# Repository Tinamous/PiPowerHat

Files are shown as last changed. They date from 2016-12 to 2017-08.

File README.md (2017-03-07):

Raspberry Pi Power Hat
======================

WORK IN PROGRESS - Not tested!

A Hat for the Raspberry Pi to supply 5V though the 40pin header from a 7-36V DC source rather than using the USB plug.

When using the 7" Pi Display the voltage drop across the USB cable (esp. if long) may be too much for the Pi. This hat allows a higher voltage to be dropped 
right as it is needed and distributed to the Pi and the display so reducing the voltage drop.

Rather than design and source a buck switching supply this hat uses one of the many cheap "eBay" buck converts that have the 
standard 7805 footprint (Don't use an actual 7805!).

e.g. a PM-5033-1 36 V In, 5V 2.5A Out buck converter. http://www.ebay.co.uk/itm/262241859833

The PCB also includes:
* INA219 to measure the power via a current sense resistor (R4 - value to be determined)
* The normal Pi HAT EEprom
* DS18B20 - SOIC 8 footprint by the converter to monitor PCB temperature.
* DS18B20 - TO-92 (3 Pin) to measure ambient temperature
* 3 Pin Molex header for off-board DB18B20's
* 4 Pin Molex header for Pi 7" display (GND, 5V, I2C connections).

Pi Hat original schema/PCB (connector, shape, EEprom) but Ivan Zilic (http://www.flyfish-tech.com)
Source: 
https://www.raspberrypi.org/forums/viewtopic.php?f=100&t=82618
http://www.flyfish-tech.com/pub/RasPi-BplusHAT.zip

Component Libraries:
SparkFun - https://github.com/sparkfun/SparkFun-Eagle-Libraries
DS18B20-SOIC - ??
INA219 - Farnell

See https://github.com/Tinamous/OctoPrint-PiPower for an OctoPrint plugin to monitor and control.

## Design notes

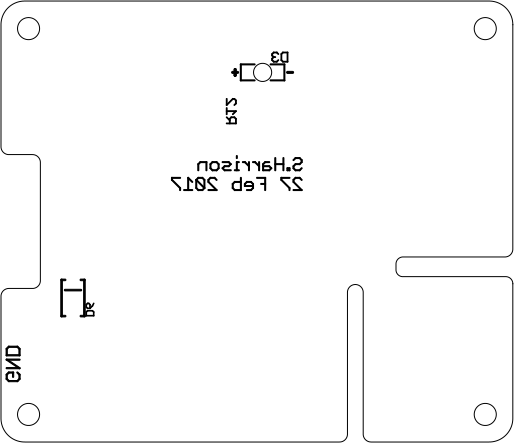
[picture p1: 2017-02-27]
Images/V1.2/bottom_silkscreen.png

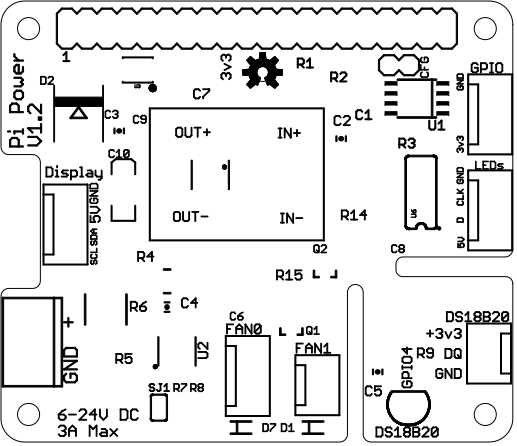
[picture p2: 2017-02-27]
Images/V1.2/top_silkscreen.png

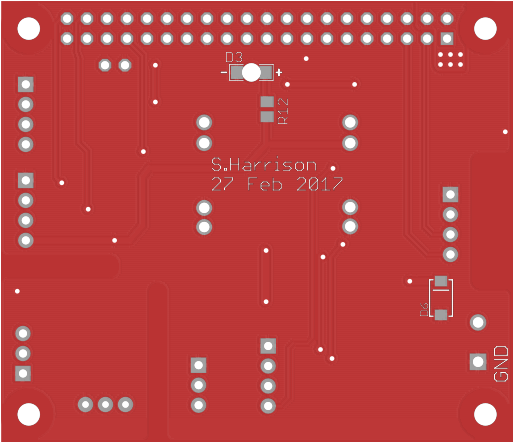
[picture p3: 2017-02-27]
Images/V1.2/bottom.png

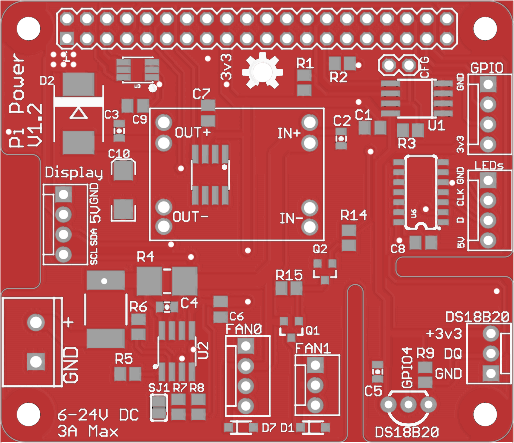
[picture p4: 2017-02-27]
Images/V1.2/top.png

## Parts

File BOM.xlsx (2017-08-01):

Big Lathcing Relat. Version 1. Bill of Materials
Part | Value | Case | QTY | Price Each | Price Total | Farnell Part Number | Reel | Mouser | Notes
C5 | 1uF | "0805" | 1 | 0.0291 | 0.0291 | 2320853 | 2310412
C1 | 10uF Tant | "Case A" | 1 | 0.106 | 0.106 | 1457413
R1 | 1k5 | "1206" | 1 | 0.0013 | 0.0013 | 9335951 | 2129658
D2 | Reverse LED Blue | "1206" | 1 | 0.23 | 0.23 | 2217907
CONN1 | USB A Plug |  | 1 | 0.35 | 0.35 | 2476092
JP1 | 3 Way terminal block | header | 1 | 0.107 | 0.107 | 2493690
JP1b | 3 Way terminal block | pluggable-12AWG | 1 | 0.267 | 0.267 | 2493638
U1 | Latching relay |  | 1 | 2.16 | 2.16 | 2432863
U2 | Photon or Electron |  | 0 | 20 | 0
U2a | Headers 12W |  | 2 | 0.0911 | 0.1822 | 1593465
U2b | Headers 18W |  | 0 | 1.11 | 0 | 1801220
U3 | BD6211F-E2 |  | 1 | 1.05 | 1.05 | 1716259
 | PCB |  | 1 | 1.5 | 1.5
 |  |  |  |  | 5.9826
 |  |  |  | Wholesale: | 11.9652
 |  |  |  | Retail | 23.9304

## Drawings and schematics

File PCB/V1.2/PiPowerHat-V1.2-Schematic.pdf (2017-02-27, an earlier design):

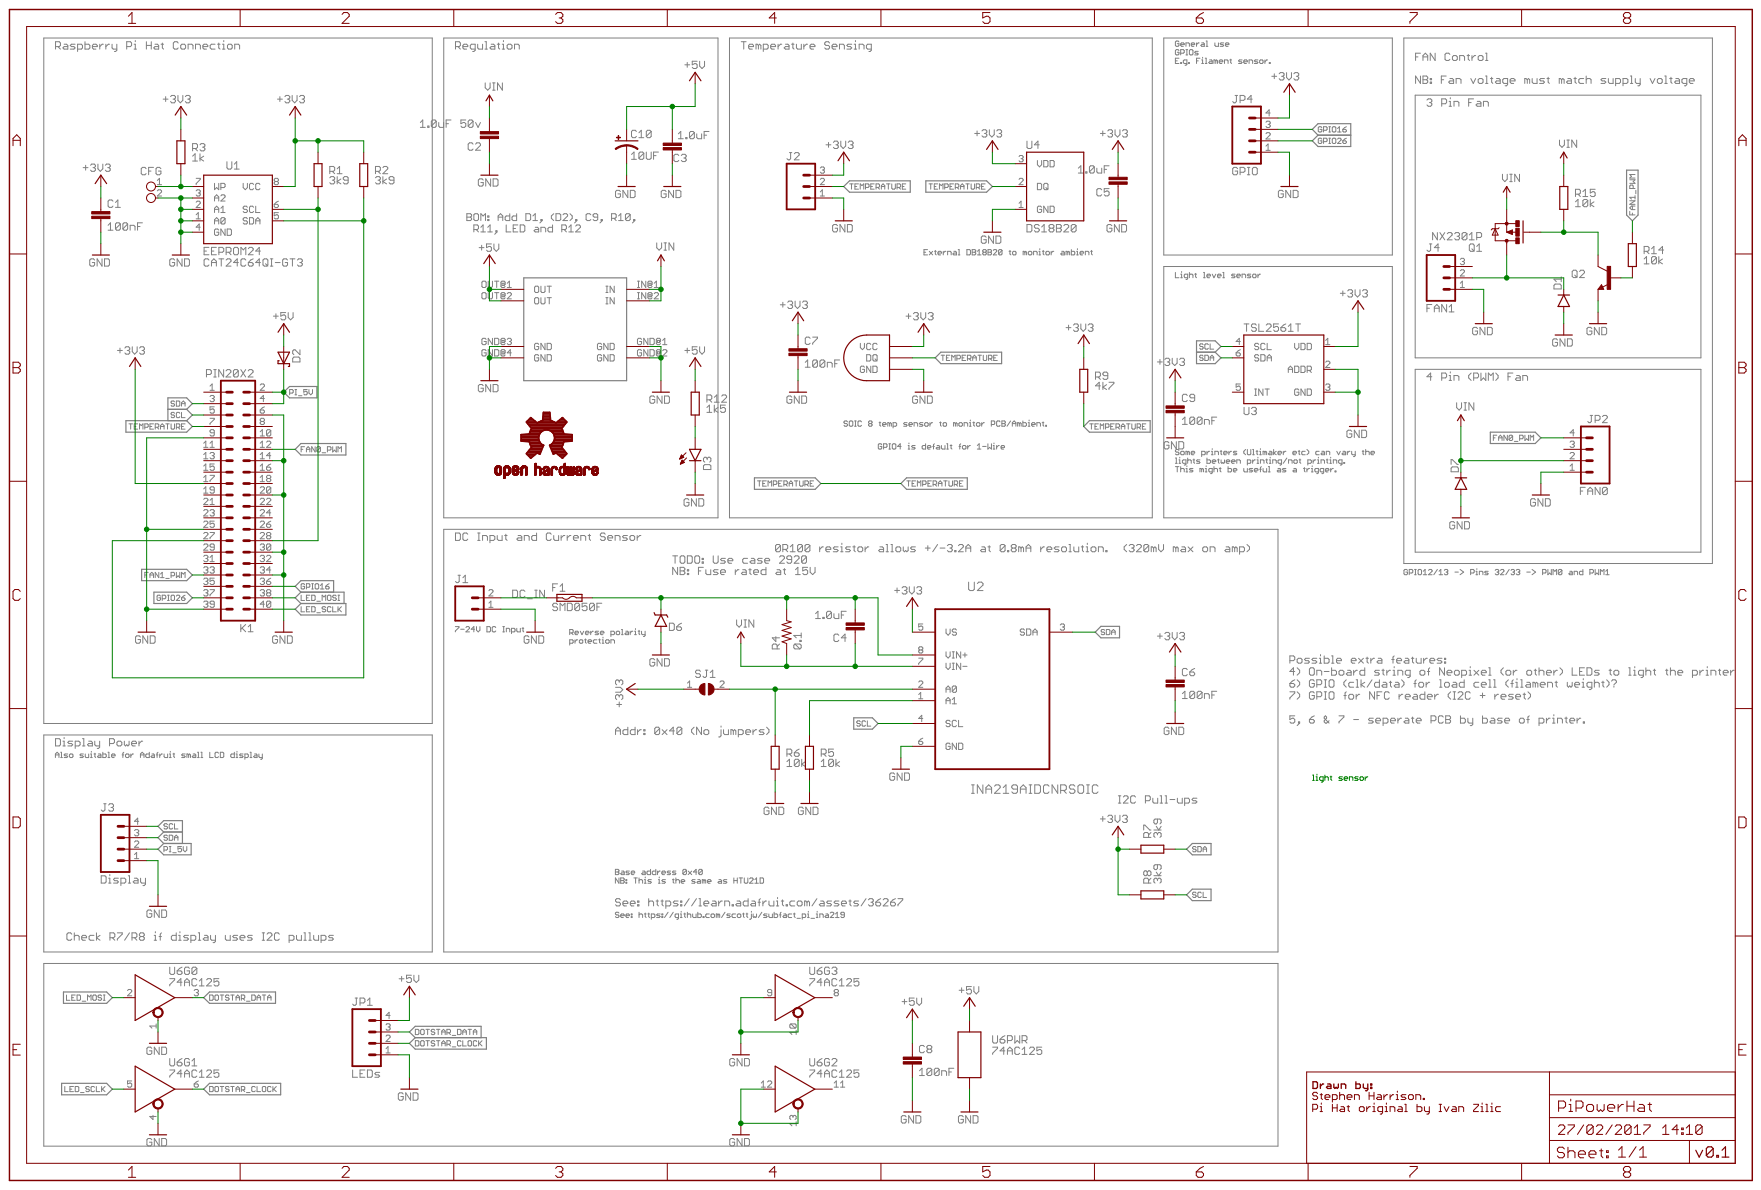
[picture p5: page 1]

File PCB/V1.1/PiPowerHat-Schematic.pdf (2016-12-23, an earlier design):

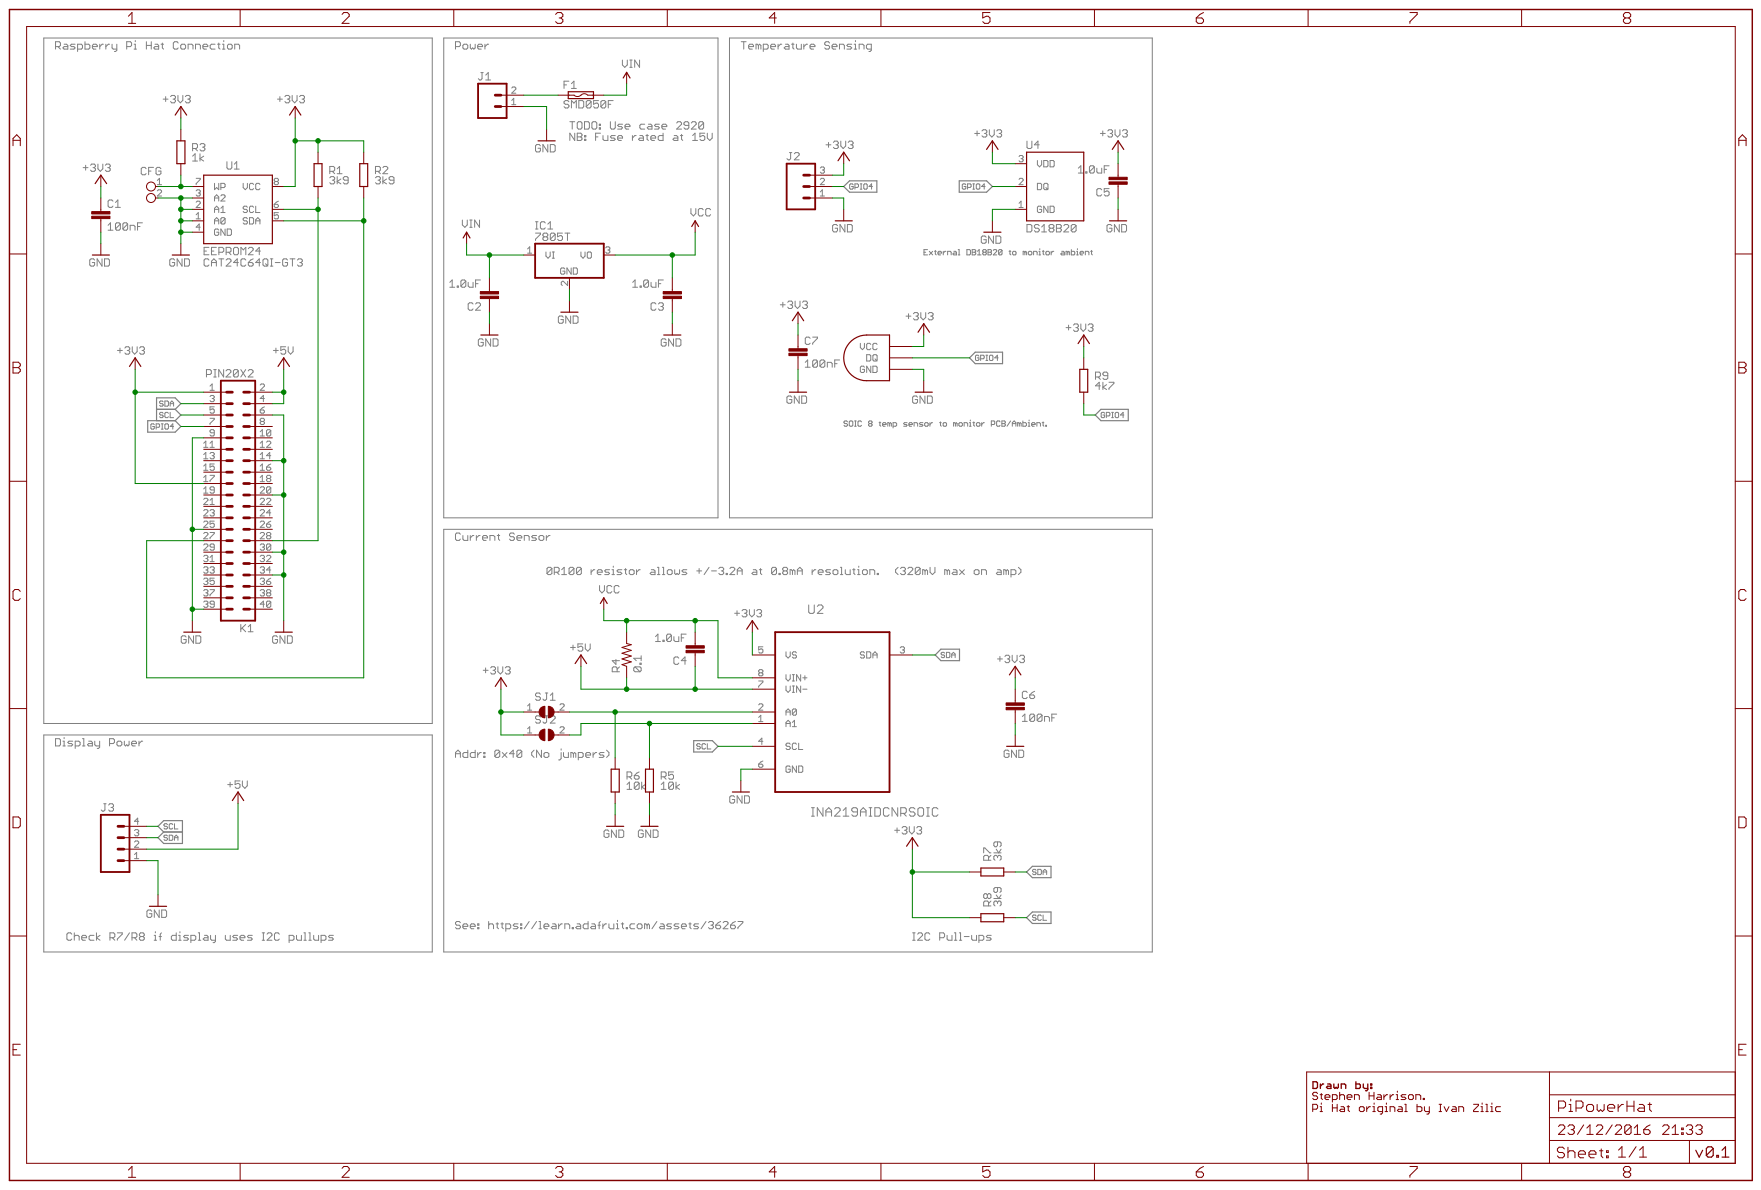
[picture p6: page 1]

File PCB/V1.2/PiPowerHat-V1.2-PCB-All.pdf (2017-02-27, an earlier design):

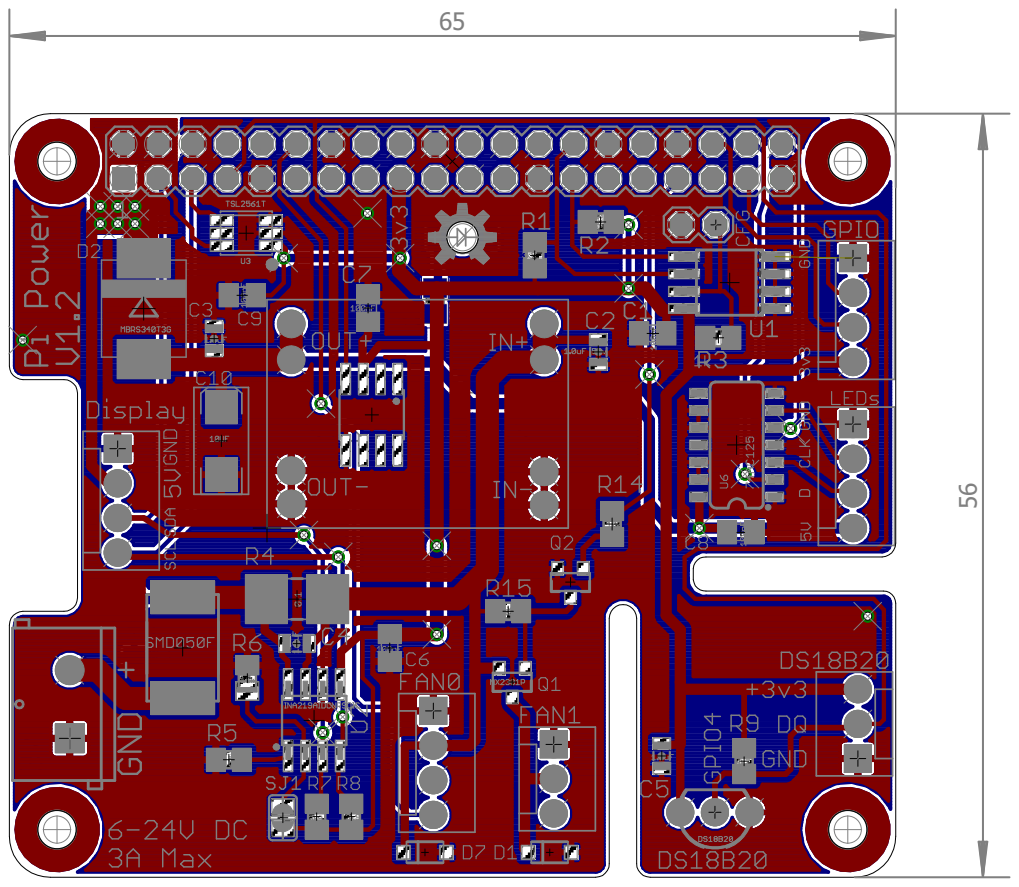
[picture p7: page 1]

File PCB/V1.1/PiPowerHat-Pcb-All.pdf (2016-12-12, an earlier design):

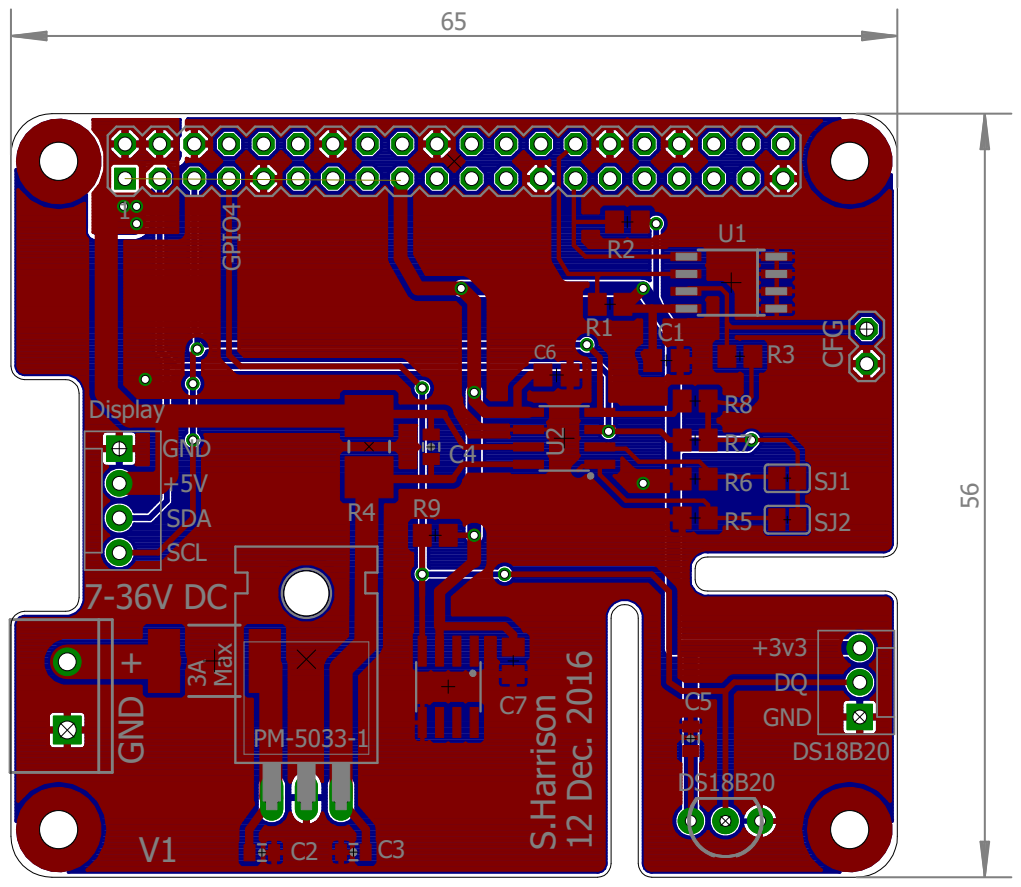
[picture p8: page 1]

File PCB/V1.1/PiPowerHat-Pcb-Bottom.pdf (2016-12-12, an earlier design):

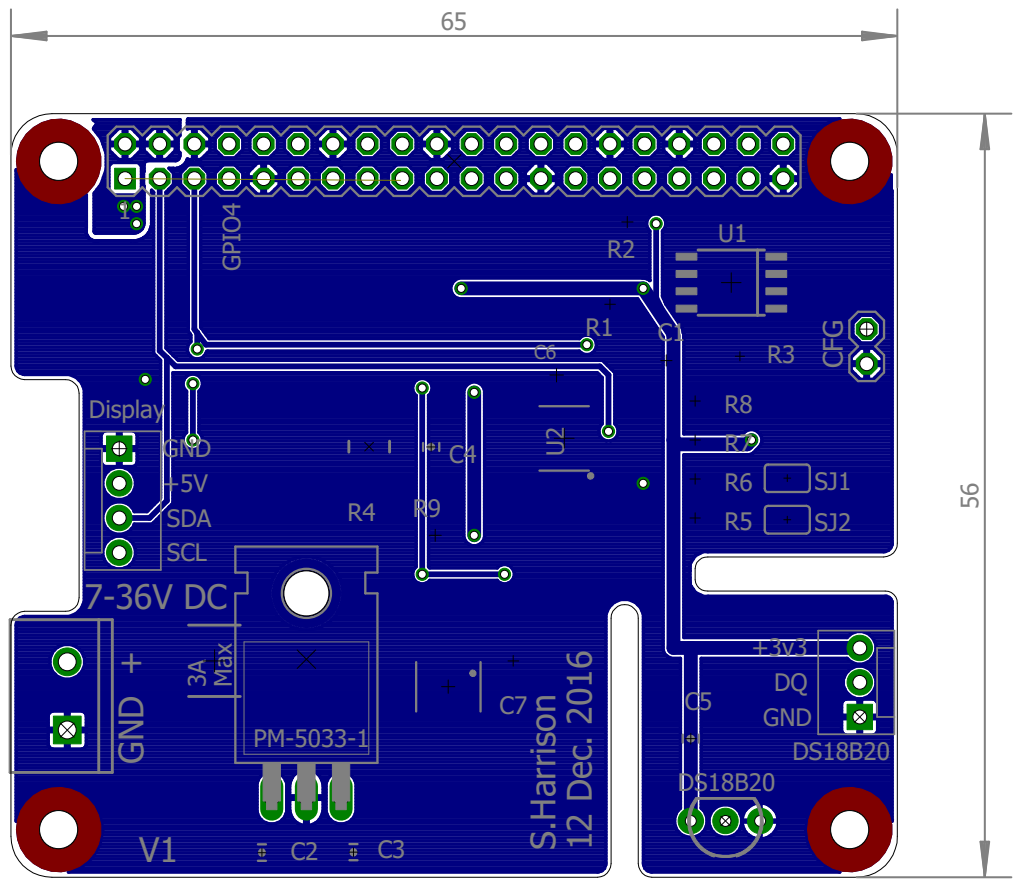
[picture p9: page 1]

SDA | R9

SCL

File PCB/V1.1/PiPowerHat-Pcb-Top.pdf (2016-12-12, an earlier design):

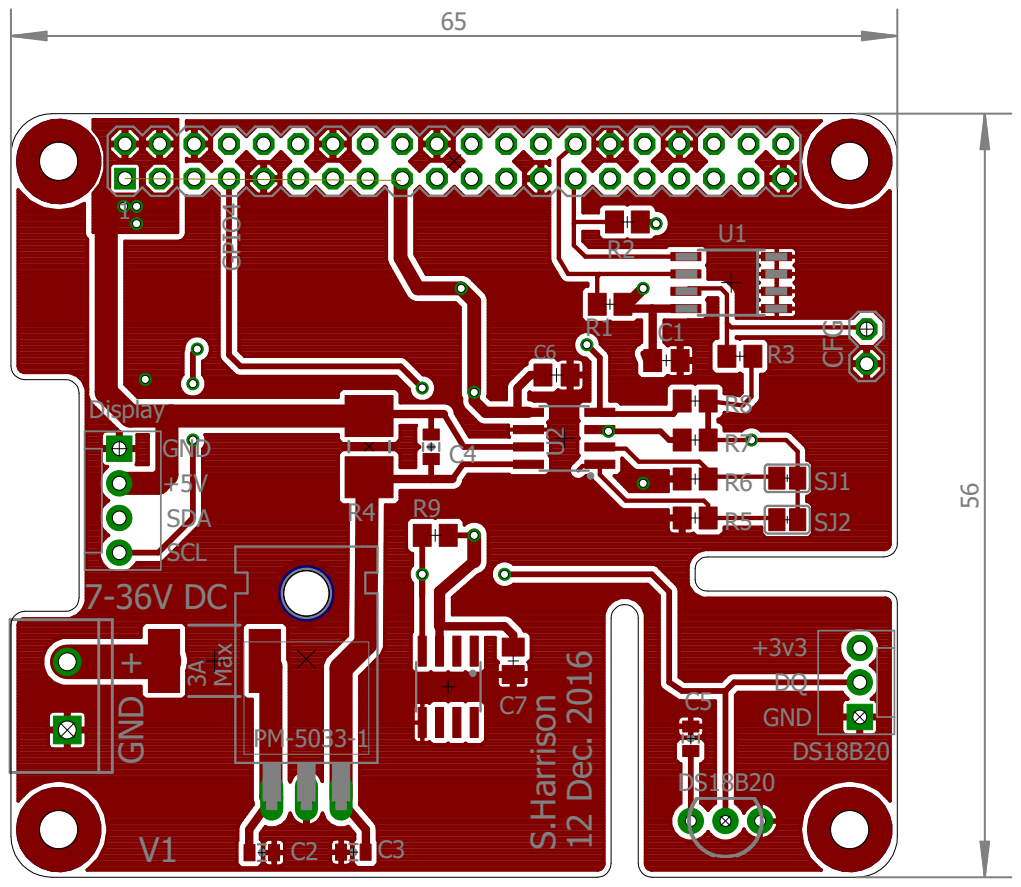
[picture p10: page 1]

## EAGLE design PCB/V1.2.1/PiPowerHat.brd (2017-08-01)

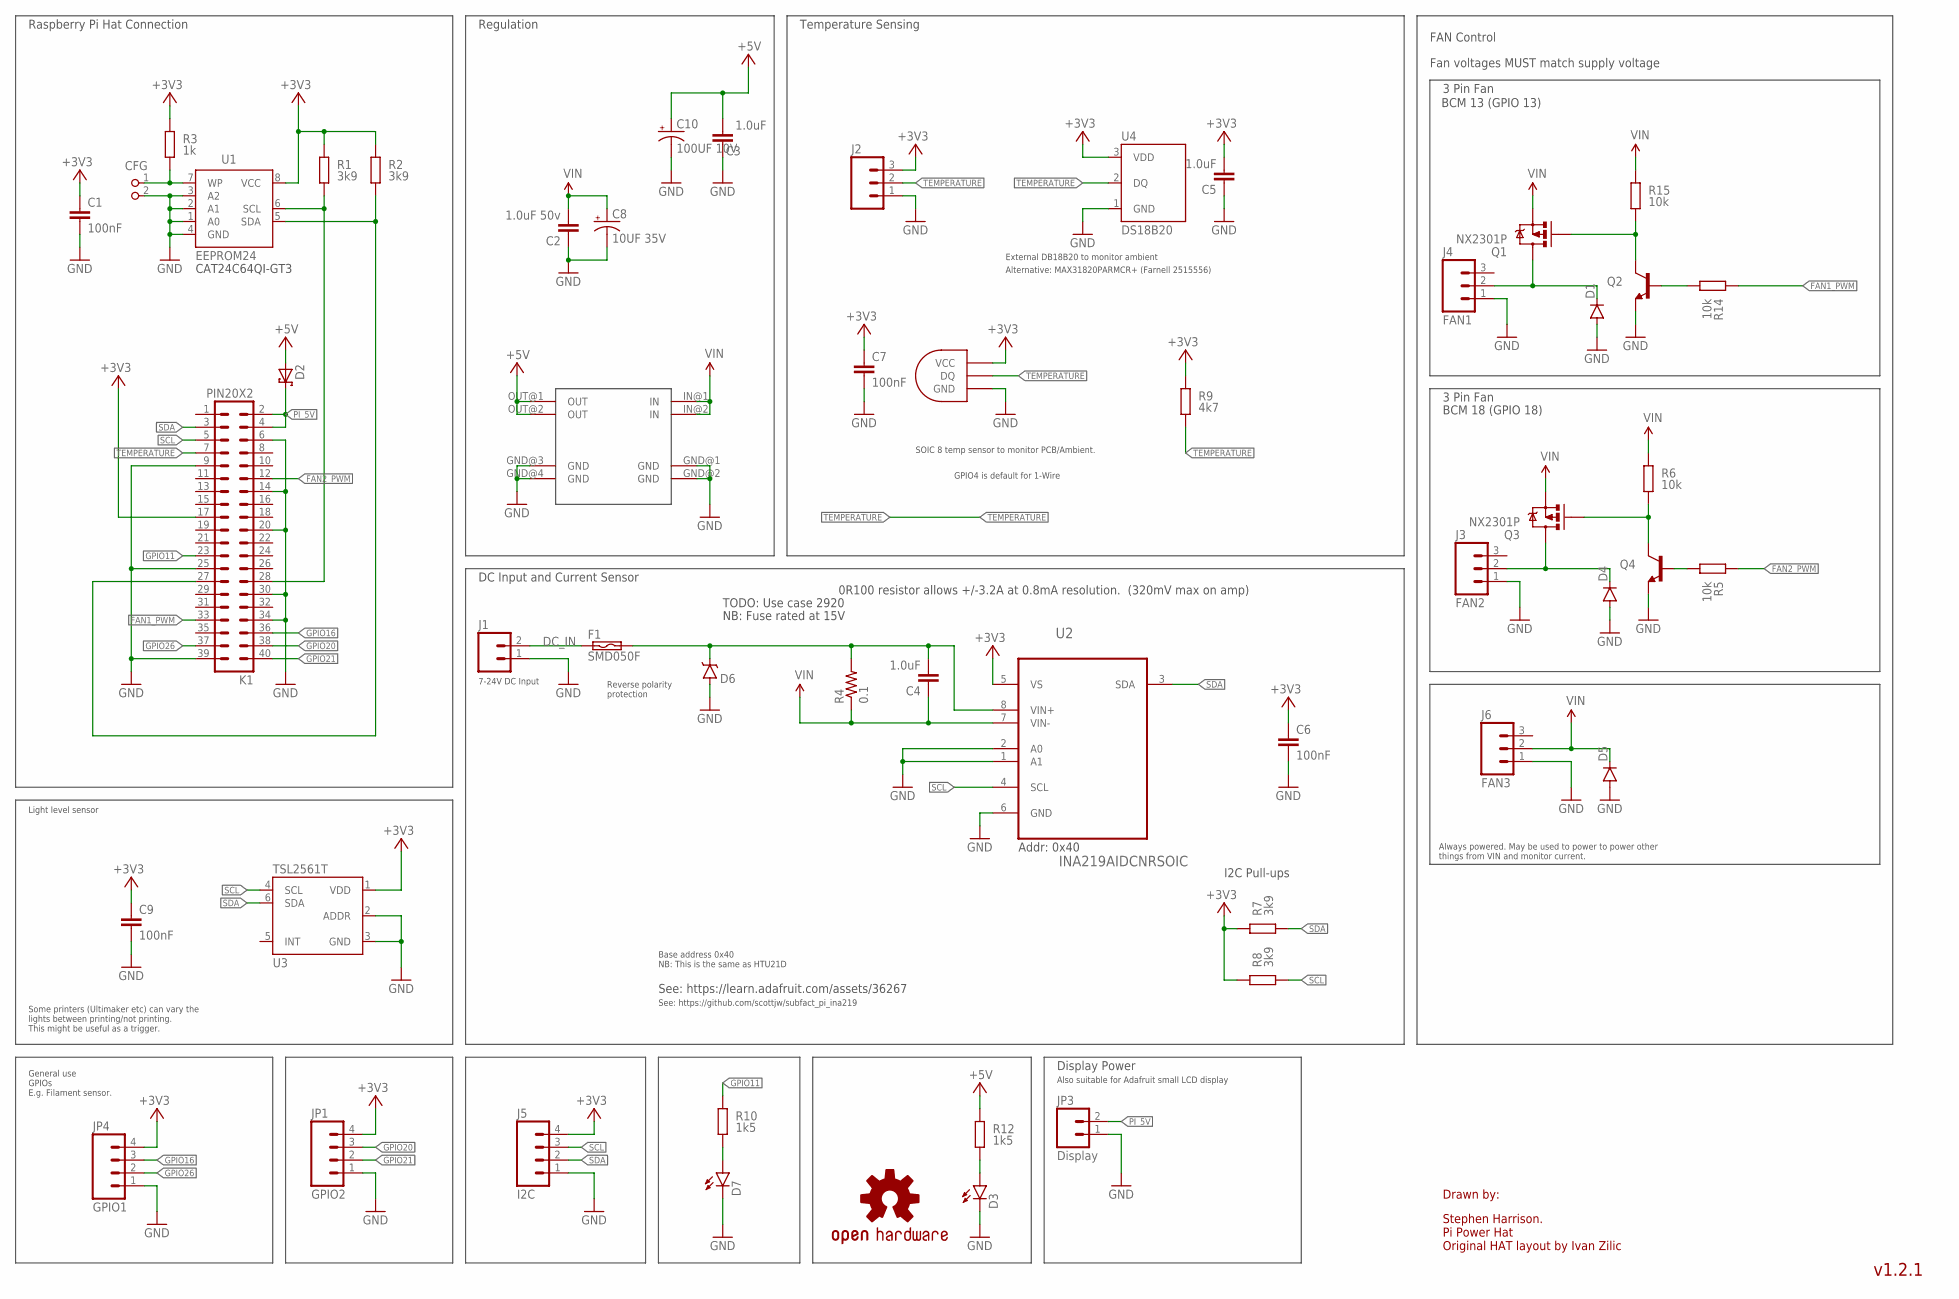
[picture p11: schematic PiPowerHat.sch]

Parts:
C1, C6, C7, C9: 100nF; C0805K
C2: 1.0uF 50v; 0805-CAP
C3, C4, C5: 1.0uF; 0805-CAP
C8: 10UF 35V; EIA6032-NOM; FARNELL 197634
C10: 100UF 10V; EIA6032-NOM
CFG: PIN2_100; PIN_W_2
D1, D4, D5: DIODESOD123; SOD-123
D2: MBRS340T3G; SMC; FARNELL 9557377
D3: LED1206-BOTTOM; LED-1206-BOTTOM
D6: B340A; SMA-DIODE
D7: LED1206; LED-1206
F1: SMD050F; FARNELL 1822231
J1: M025MM; SCREWTERMINAL-5MM-2
J2: M03POLAR; MOLEX-1X3
J3: FAN2; MOLEX-1X3
J4: FAN1; MOLEX-1X3
J5: I2C; MOLEX-1X4
J6: FAN3; MOLEX-1X3
JP1: GPIO2; MOLEX-1X4
JP3: Display; MOLEX-1X2
JP4: GPIO1; MOLEX-1X4
K1: PIN20X2; PIN_20X2
LOGO1: OSHW-LOGOM; OSHW-LOGO-M
Q1, Q3: NX2301P; SOT23-3
Q2, Q4: TRANSISTOR_NPNSOT23-3; SOT23-3
R1, R2, R7, R8: 3k9; M0805; TOLERANCE 5%
R3: 1k; M0805; TOLERANCE 5%
R4: 0.1; 2512
R5, R6, R14, R15: 10k; M0805; TOLERANCE 5%
R9: 4k7; M0805; TOLERANCE 5%
R10, R12: 1k5; M0805; TOLERANCE 5%
RG1: MINI-BUCK-MODULE-3A
U1: EEPROM24; SOIC8; FARNELL 2463718
U2: INA219AIDCNRSOIC; SO08
U3: TSL2561T; TMB-6
U4: DS18B20; TO-92-AMMO
U5: DS1820SOIC; DS18B20_SOIC

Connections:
+3V3: C1.1, C5.2, C6.1, C7.1, C9.1, J2.3, J5.4, JP1.4, JP4.4, K1.17, R1.2, R2.2, R3.2, R7.2, R8.2, R9.2, U1.8 (VCC), U2.5 (VS), U3.1 (VDD), U4.3 (VDD), U5.VCC
+5V: C3.2, C10.A (+), D2.A, R12.2, RG1.OUT@1 (OUT), RG1.OUT@2 (OUT)
DC_IN: F1.1, J1.2
FAN1_PWM: K1.33, R14.2
FAN2_PWM: K1.12, R5.2
GND: C1.2, C2.1, C3.1, C5.1, C6.2, C7.2, C8.C (-), C9.2, C10.C (-), CFG.2, D1.A, D3.C, D4.A, D5.A, D6.A, D7.C, J1.1, J2.1, J3.1, J4.1, J5.1, J6.1, JP1.1, JP3.1, JP4.1, K1.6, K1.9, K1.14, K1.20, K1.25, K1.30, K1.34, K1.39, Q2.2 (E), Q4.2 (E), RG1.GND@1 (GND), RG1.GND@2 (GND), RG1.GND@3 (GND), RG1.GND@4 (GND), U1.1 (A0), U1.2 (A1), U1.3 (A2), U1.4 (GND), U2.1 (A1), U2.2 (A0), U2.6 (GND), U3.2 (ADDR), U3.3 (GND), U4.1 (GND), U5.GND
GPIO11: K1.23, R10.2
GPIO16: JP4.3, K1.36
GPIO20: JP1.3, K1.38
GPIO21: JP1.2, K1.40
GPIO26: JP4.2, K1.37
ID_SC: K1.28, R1.1, U1.6 (SCL)
ID_SD: K1.27, R2.1, U1.5 (SDA)
unnamed: D4.C, J3.2, Q3.3 (D)
unnamed: Q4.1 (B), R5.1
unnamed: CFG.1, R3.1, U1.7 (WP)
unnamed: D3.A, R12.1
unnamed: C4.2, D6.C, F1.2, R4.2, U2.8 (VIN+)
unnamed: Q3.1 (G), Q4.3 (C), R6.1
unnamed: D1.C, J4.2, Q1.3 (D)
unnamed: Q1.1 (G), Q2.3 (C), R15.1
unnamed: D7.A, R10.1
unnamed: Q2.1 (B), R14.1
PI_5V: D2.C, JP3.2, K1.2, K1.4
SCL: J5.3, K1.5, R8.1, U2.4 (SCL), U3.4 (SCL)
SDA: J5.2, K1.3, R7.1, U2.3 (SDA), U3.6 (SDA)
TEMPERATURE: J2.2, K1.7, R9.1, U4.2 (DQ), U5.DQ
VIN: C2.2, C4.1, C8.A (+), D5.C, J6.2, Q1.2 (S), Q3.2 (S), R4.1, R6.2, R15.2, RG1.IN@1 (IN), RG1.IN@2 (IN), U2.7 (VIN-)

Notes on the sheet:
Drawn by:
Stephen Harrison. Pi Power Hat Original HAT layout by Ivan Zilic
v1.2.1
SOIC 8 temp sensor to monitor PCB/Ambient.
External DB18B20 to monitor ambient
CAT24C64QI-GT3
I2C Pull-ups
Temperature Sensing
Regulation
Raspberry Pi Hat Connection
Display Power
DC Input and Current Sensor
See: https://learn.adafruit.com/assets/36267
0R100 resistor allows +/-3.2A at 0.8mA resolution. (320mV max on amp)
Addr: 0x40
TODO: Use case 2920
NB: Fuse rated at 15V
Reverse polarity protection
7-24V DC Input
Base address 0x40 NB: This is the same as HTU21D
See: https://github.com/scottjw/subfact_pi_ina219
GPIO4 is default for 1-Wire
FAN Control
3 Pin Fan
Fan voltages MUST match supply voltage
General use GPIOs E.g. Filament sensor.
Also suitable for Adafruit small LCD display
Light level sensor
Some printers (Ultimaker etc) can vary the lights between printing/not printing. This might be useful as a trigger.
BCM 18 (GPIO 18)
BCM 13 (GPIO 13)
Always powered. May be used to power to power other things from VIN and monitor current.
Alternative: MAX31820PARMCR+ (Farnell 2515556)

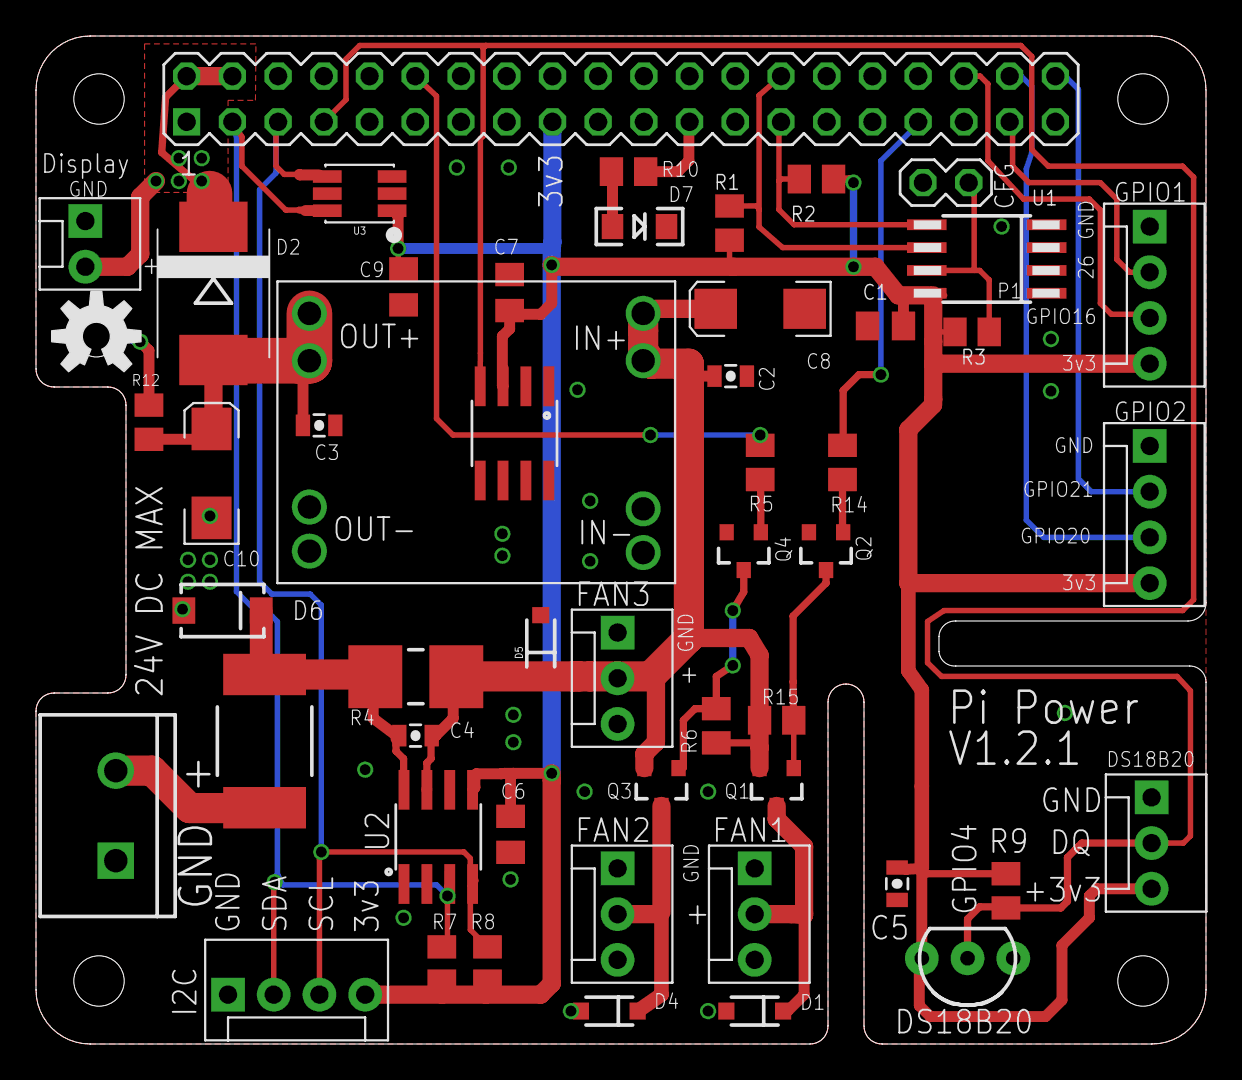
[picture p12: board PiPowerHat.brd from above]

Board: 2 copper layers, 65.0 x 56.0 mm, 53 parts (1 on the bottom side), 28 nets.

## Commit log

2016-12-12 Initial version as sent to DirtyPCBs.
    [PiPowerHat.brd, PiPowerHat.sch]
2016-12-12 Corrected dimension measurements to be on the measurements layer, not dimensions.
    Added Version and name/date.
    Printed schema and PCB to PDFs
    Added readme.
    [PiPowerHat.brd, PiPowerHat.sch]
2016-12-22 Added notes for eeprom
    [PiPowerHat.brd, PiPowerHat.sch]
2016-12-23 Tidied up schematic/board with feedback from 1st build.
    Added BOM.
    [PiPowerHat.brd, PiPowerHat.sch]
2016-12-23 Update for PTC fuse size issue
2016-12-24 Improved routing to not use bottom layer so much
    [PiPowerHat.brd, PiPowerHat.sch]
2016-12-25 Improved routing to increase ground plain, change IO pins used with option to select between 2 IO pins for temperature sensors.
    Added OSH logo and rear LED.
    [PiPowerHat.brd, PiPowerHat.sch]
2017-02-27 Changed 7805 style regulator to the 3A buck regulator.
    Added DotStar LED strip connector (clk/data).
    Added 2 GPIO port + power connector.
    Added 2x fan connectors (1x 4 pin PWM, 1x 3 pin PWM power)
    Added fuse.
    Moved current/voltage sensor to pre-regulator to monitor the input voltage.
    Moved board temperature sensor to be under regulator module.
    [PiPowerHat.brd, PiPowerHat.sch]
2017-05-17 Added pin numbers for the fans
    [PiPowerHat.sch]
2017-05-20 Documentation improvements to V1.2 PCB
    [PiPowerHat.sch]
2017-07-22 Update to rearrange the board a bit better.
    [BOM.xlsx, PiPowerHat.brd, PiPowerHat.sch]
2017-07-31 Coped V1.2 to V1.2 folder so it's easier to have multiple versions available
    [PiPowerHat.brd, PiPowerHat.sch]
2017-08-01 Removed 3v3/5V logic converter in favour of just a second 3v3 GPIO port.
    Added Fan3 which is permenantly connected to the VIn supply to allow it to be used to power a fan or something else whilst still having current monitoring without the current restriction of the p-cha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
    Slight improvements in routing.
    [PiPowerHat.brd, PiPowerHat.sch]
2017-08-01 Flipped temperature sensor connector improved silk screen.
    [PiPowerHat.brd]
2017-08-01 Updated silk screen. Sent to DirtyPCBs.
    [PiPowerHat.brd, PiPowerHat.sch]
2017-08-01 Copied V1.2.1 PCB/schematic to the 1.2.1 folder.
    [PiPowerHat.brd, PiPowerHat.sch]
2017-08-21 Added Github link to the bottom of the board.
    Ordered ENIG batch from DirtyPCBs.
    [PiPowerHat.brd]

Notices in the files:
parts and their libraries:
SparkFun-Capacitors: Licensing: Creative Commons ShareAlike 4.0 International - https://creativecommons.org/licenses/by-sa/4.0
